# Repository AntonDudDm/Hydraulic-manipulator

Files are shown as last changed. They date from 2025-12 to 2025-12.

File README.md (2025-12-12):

# Hydraulic-manipulator

Проект многоосевого роботизированного манипулятора с механической,
электронной и программной частью.

Движение манипулятора осуществляется засчет гидравлических приводов.

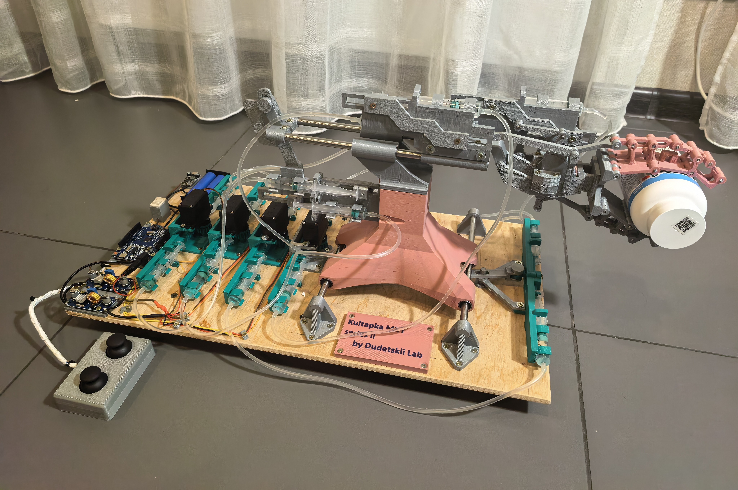
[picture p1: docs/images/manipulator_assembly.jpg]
Assembled Manipulator


## 📌 Доустигнутые цели проекта
- Моделирование кинематики и динамики
- Проектирование механической конструкции манипулятора
- Разработка управляющего ПО
- Управление сервоприводами / моторами
- Создание реального прототипа

## Структура проекта
```
Hydraulic-manipulator/
├── cad/ # SolidWorks модели (детали, сборки, чертежи)
├── firmware/ # Код микроконтроллера
├── software/ # ПК-скрипт для управления с компьютера
├── simulations/ # Математическое моделирование
└── docs/ # Документация, необходимые запчасти
```

## ⭐ Преимущества данного манипулятора

### 1️⃣ Преимущества, обусловленные гидравлическим приводом

Использование гидравлического привода обеспечивает ряд ключевых преимуществ по сравнению с электрическими и пневматическими системами:

* **Высокая удельная мощность**
  Гидравлические приводы позволяют развивать большие усилия и моменты при компактных габаритах исполнительных механизмов, что особенно важно для манипуляторов, работающих с тяжёлыми объектами.

* **Плавность и непрерывность движения**
  Гидравлика обеспечивает устойчивое и плавное управление скоростью и усилием, что критично при выполнении точных операций захвата и позиционирования.

* **Устойчивость к перегрузкам**
  В отличие от электроприводов, гидравлические системы лучше переносят кратковременные перегрузки без риска повреждения двигателя или редуктора.

* **Работоспособность в экстремальных условиях**
  Гидравлические системы менее чувствительны к:

  * высокой влажности,
  * пыли и загрязнениям,
  * вибрациям,
  * перепадам температур,
    что делает манипулятор пригодным для промышленной и полевой эксплуатации.

* **Высокая надёжность при длительной работе**
  При корректном проектировании гидросистема обладает большим ресурсом и стабильными характеристиками во времени.

---

### 2️⃣ Универсальная конструкция захвата

Особая конструкция хвата манипулятора обеспечивает возможность работы с широким спектром объектов:

* **Захват предметов различной формы и размеров**
  Конструкция позволяет эффективно работать как с:

  * цилиндрическими,
  * плоскими,
  * угловыми,
  * несимметричными объектами.

* **Адаптивность к положению объекта**
  Захват компенсирует неточности позиционирования и допускает небольшие ошибки ориентации, снижая требования к точности наведения манипулятора.

* **Надёжное удержание при минимальном давлении**
  Геометрия и кинематика хвата позволяют равномерно распределять усилие, уменьшая риск повреждения хрупких предметов.

* **Расширение области применения**
  Универсальный хват делает манипулятор пригодным как для:

  * технических,
  * так и для исследовательских и сервисных задач.

---

### 3️⃣ Дистанционное размещение гидравлических приводов

Конструкция манипулятора допускает вынос гидравлических приводов (насосов и моторов) за пределы рабочей зоны, что даёт принципиальные преимущества:

* **Повышенная безопасность эксплуатации**
  Манипулятор может работать в условиях:

  * радиационного заражения,
  * химически агрессивной среды,
  * повышенной температуры,
  * взрывоопасных зон,
    при этом основные силовые элементы остаются вне опасной области.

* **Снижение массы подвижных звеньев**
  Отсутствие тяжёлых моторов на самом манипуляторе:

  * уменьшает инерцию,
  * снижает нагрузки на конструкцию,
  * повышает точность и динамику движений.

* **Упрощение конструкции манипулятора**
  Механическая часть становится легче и конструктивно проще, что:

  * облегчает масштабирование,
  * повышает ремонтопригодность,
  * снижает требования к несущим элементам.

* **Повышение надёжности и ресурса системы**
  Дистанционное размещение приводов уменьшает тепловые и вибрационные нагрузки на манипулятор и электронные компоненты управления.

---

### 📌 Итог

Совокупность гидравлического привода, универсального хвата и возможности дистанционного размещения силовых элементов делает манипулятор:

* мощным,
* адаптивным,
* безопасным,
* пригодным для работы в экстремальных и потенциально опасных условиях.

Такая архитектура особенно перспективна для промышленной автоматизации, аварийно-спасательных и исследовательских задач.

---

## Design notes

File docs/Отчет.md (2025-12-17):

# Отчёт по разработке робототехнического манипулятора с гидравлическим приводом

## 1. Введение

В рамках инженерной подготовки была выполнена разработка робототехнического манипулятора, соответствующего заданной кинематической схеме. Проект охватывал полный цикл инженерной разработки: от анализа кинематики и концептуального проектирования до изготовления, сборки, электроники и программного управления.

Ключевой особенностью проекта является **использование полностью гидравлической системы привода**, реализованной на базе доступных компонентов и аддитивных технологий, что позволило исследовать альтернативные решения по сравнению с классическими электрическими и механическими приводами.

Assembled Manipulator

---

## 2. Цель и задачи работы

### 2.1 Цель работы

**Создание функционирующего робототехнического манипулятора, соответствующего заданной кинематической схеме, с использованием гидравлических приводов и электронного управления.**

---

### 2.2 Задачи работы

Для достижения поставленной цели в рамках проекта были решены следующие задачи:

1. Анализ заданной кинематической схемы манипулятора.
2. Разработка концепции механической реализации степеней свободы.
3. Исследование и сравнение различных типов приводов и передач.
4. Проектирование гидравлической системы привода.
5. Разработка механических узлов: кареток, направляющих, вращательных осей.
6. Проектирование и изготовление захватного устройства.
7. Изготовление деталей методом 3D-печати.
8. Разработка электрической схемы управления.
9. Реализация программного управления манипулятором.
10. Интеграция системы управления с клавиатурой и джойстиком.
11. Проведение финальных испытаний и анализа полученного результата.

---

## 3. Анализ кинематической схемы

На первом этапе был выполнен анализ заданной кинематической схемы манипулятора. Были определены:

* количество степеней свободы;
* типы кинематических пар (поступательные и вращательные);
* пространственное расположение осей;
* требования к диапазонам перемещений.

Анализ показал необходимость:

* реализации линейных перемещений с высокой плавностью;
* обеспечения вращательной степени свободы с достаточной жёсткостью;
* компактного и универсального схвата.

Результаты анализа легли в основу выбора конструктивных решений на последующих этапах.

---

## 4. Создание концепта и выбор механических решений

### 4.1 Концепция линейных перемещений

Для реализации поступательных степеней свободы были рассмотрены два варианта:

1. **Перемещение по направляющим с линейными подшипниками**
2. **Скользящее перемещение в пазах с сухим трением**

В ходе анализа и предварительных испытаний было установлено, что вариант с сухим трением:

* обладает повышенным сопротивлением движению;
* быстро изнашивается;
* снижает точность и повторяемость перемещений.

**Итоговое решение:**
Выбран вариант с **направляющими из нержавеющей стали и линейными подшипниками**, обеспечивающий минимальное трение, высокую плавность и долговечность.

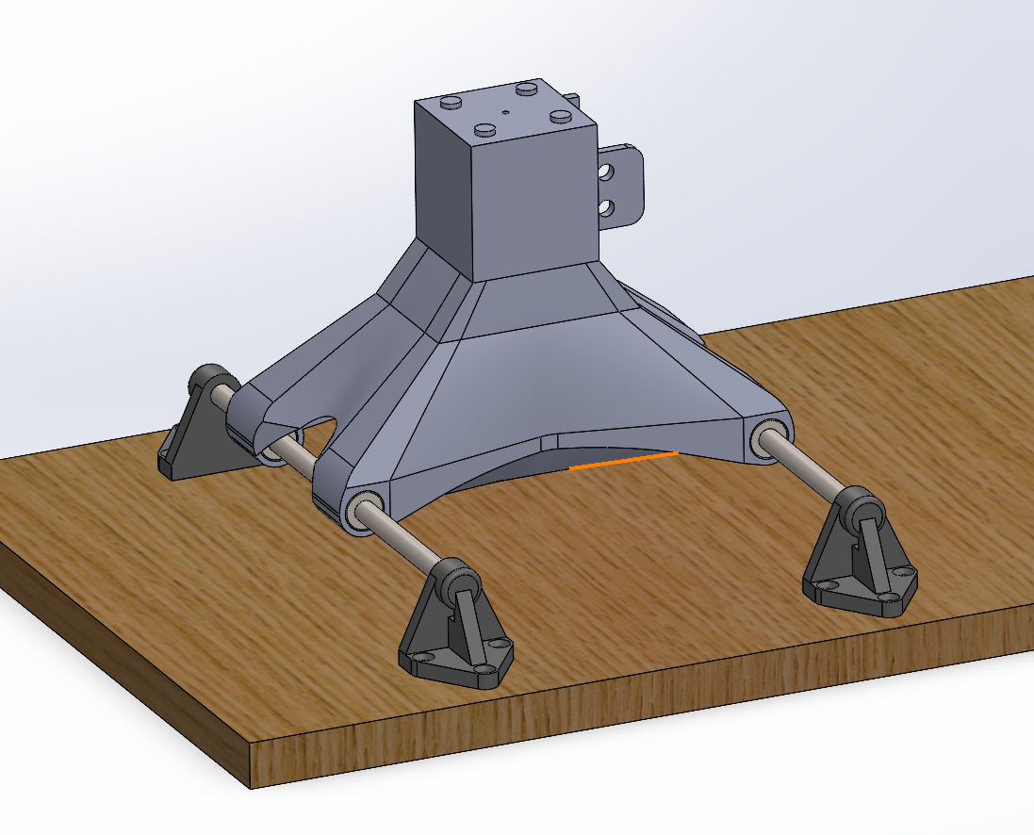
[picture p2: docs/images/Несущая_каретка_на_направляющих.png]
Несущая каретка


---

### 4.2 Выбор типа привода

Были рассмотрены следующие типы приводов:

* ремённая передача;
* винтовая передача;
* реечная передача;
* гидравлический привод.

#### Сравнение вариантов:

| Тип привода | Преимущества | Недостатки |
| --- | --- | --- |
| Ремённый | Простота, скорость | Люфты, растяжение |
| Винтовой | Точность | Сложность, трение |
| Реечный | Жёсткость | Шум, износ |
| Гидравлический | Большая сила, плавность, гибкость компоновки | Сложность герметизации |

**Итоговое решение:**
Выбран **гидравлический привод**, так как он:

* обеспечивает высокую выходную силу;
* позволяет легко преобразовывать вращательное движение в линейное;
* допускает вынесение приводов на расстояние от исполнительных механизмов;
* подходит для потенциальной работы в опасных условиях (радиация, загрязнения).

---

## 5. Разработка гидравлической системы

### 5.1 Комбинированные варианты

На ранних этапах рассматривались гибридные решения:

* гидравлика + механическая передача;
* гидравлика + тросовая передача.

Однако они показали:

* усложнение конструкции;
* рост люфтов;
* снижение надёжности.

### 5.2 Полностью гидравлическая система

В результате было принято решение о реализации **полностью гидравлической системы**.

---

### 5.3 Выбор конфигурации гидроцилиндров

Рассматривались два варианта:

1. **Одноцилиндровая система**
2. **Двуцилиндровая система**

В ходе тестирования было установлено, что:

* одноцилиндровая система имеет неравномерное распределение усилий;
* двуцилиндровая система обеспечивает лучшую симметрию, устойчивость и плавность.

**Итог:** выбран **двуцилиндровый вариант**.

---

### 5.4 Разработка гидронасоса

Из-за невозможности напечатать герметичный цилиндр на используемом 3D-принтере было принято инженерное решение:

* использовать **медицинские шприцы** как готовые герметичные гидроцилиндры.

Был разработан **двуцилиндровый гидронасос на основе шприцов**, обеспечивающий:

* надёжную герметизацию;
* простоту изготовления;
* повторяемость параметров.

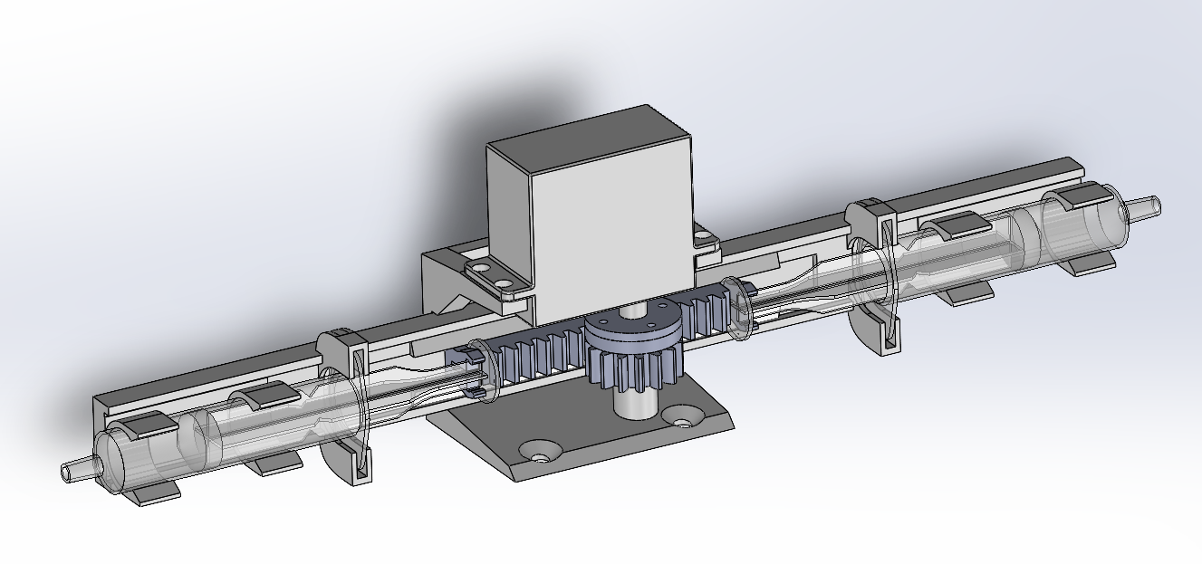
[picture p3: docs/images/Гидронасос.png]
Гидронасос


---

## 6. Проектирование механических узлов

### 6.1 Каретки и направляющие

Были разработаны:

* подвижные каретки;
* узлы крепления направляющих;
* посадочные места для линейных подшипников.

Особое внимание уделялось:

* жёсткости конструкции;
* минимизации перекосов;
* простоте сборки и обслуживания.

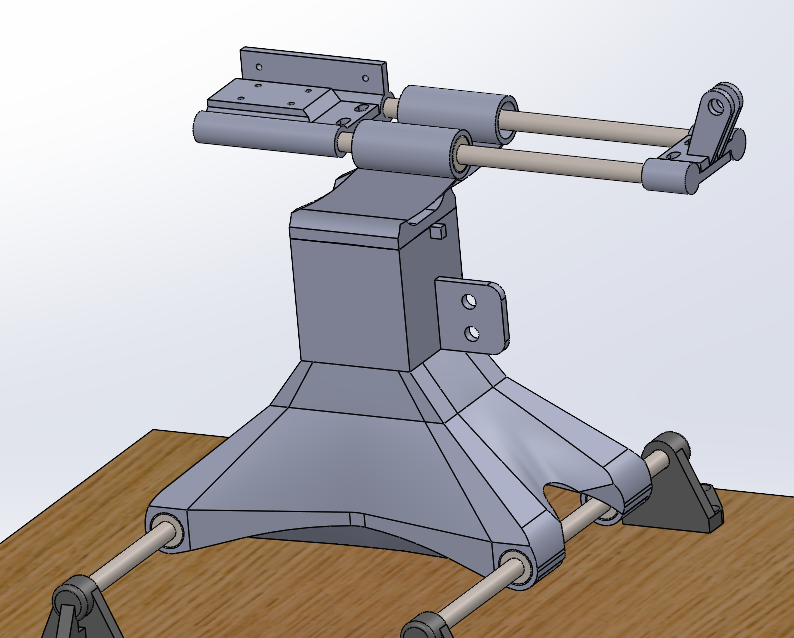
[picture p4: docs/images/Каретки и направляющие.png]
Каретки


---

### 6.2 Линейные гидромоторы

Для каждой линейной оси были разработаны гидравлические приводы, передающие усилие напрямую на каретки, что позволило отказаться от промежуточных механических передач.

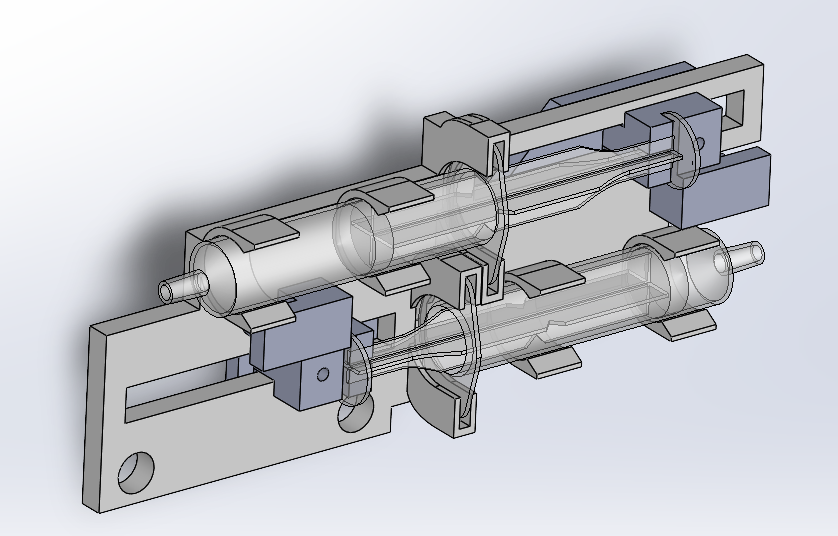
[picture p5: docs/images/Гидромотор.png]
Гидромотор


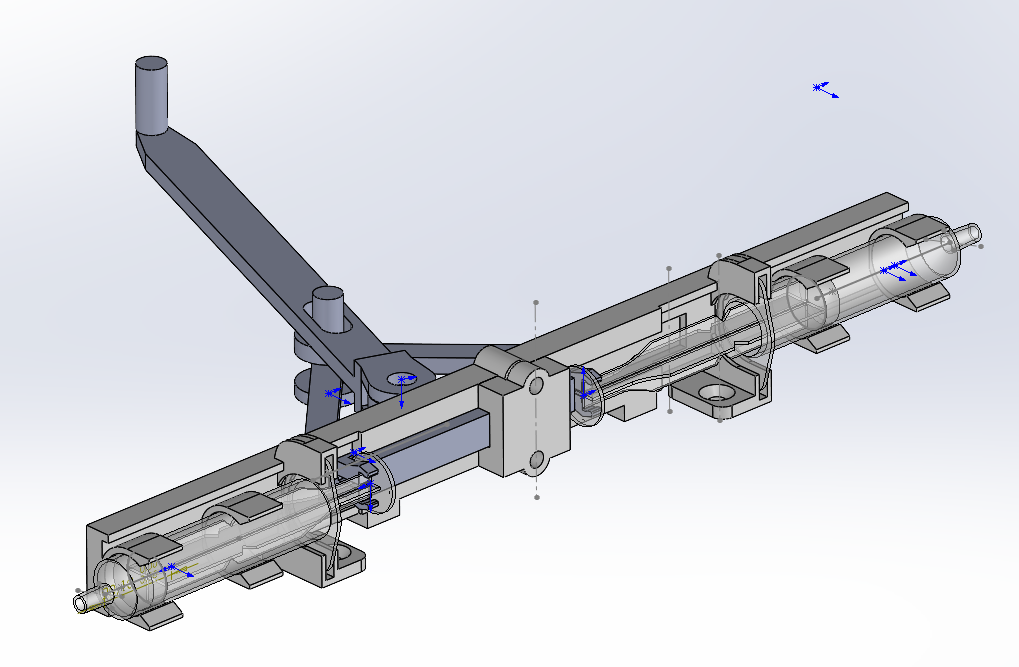
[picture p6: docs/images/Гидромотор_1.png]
Гидромотор


---

### 6.3 Вращательная ось

Первая версия вращательной оси показала:

* избыточную подвижность;
* наличие люфтов под нагрузкой.

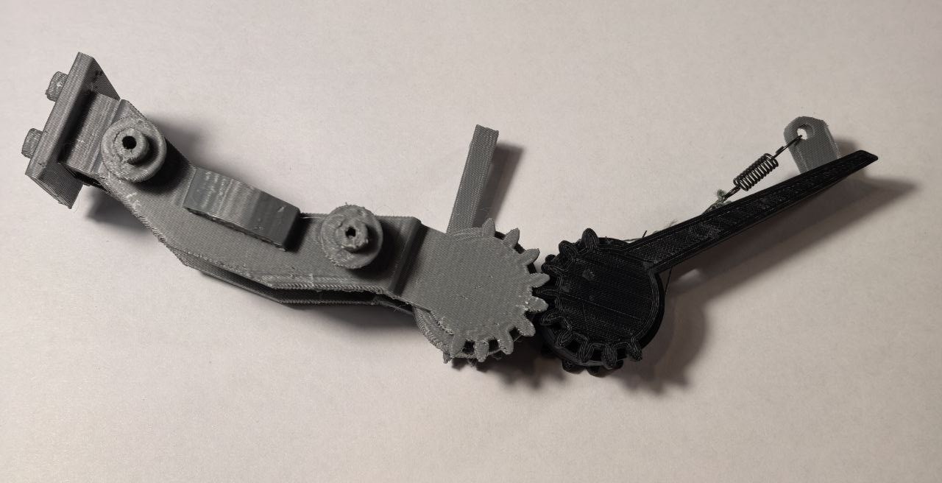
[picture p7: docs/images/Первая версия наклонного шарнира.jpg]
Шарнир версия 1


После анализа была разработана **упрощённая и более жёсткая конструкция с одной тягой**, обеспечивающая:

* снижение люфтов;
* повышение надёжности;
* упрощение сборки.

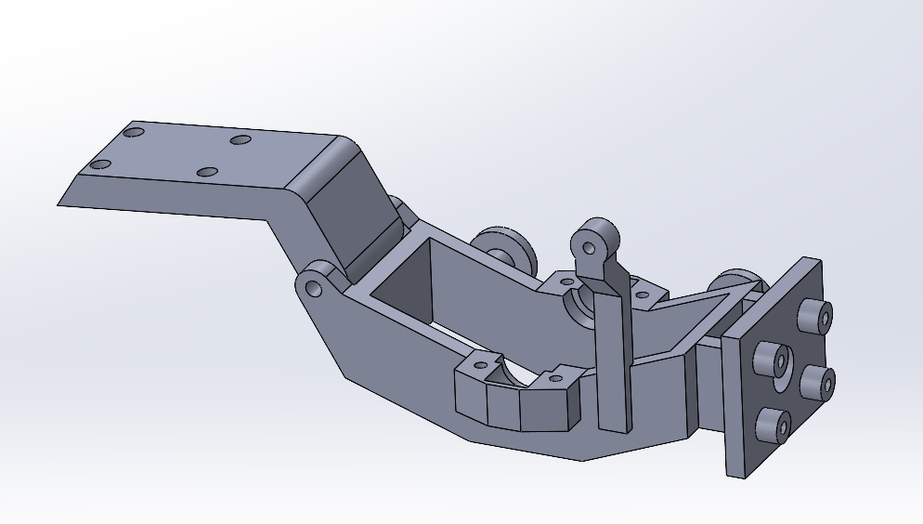
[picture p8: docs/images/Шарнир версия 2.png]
Шарнир версия 2


---

## 7. Проектирование захватного устройства

### 7.1 Анализ типов захватов

Были рассмотрены:

* параллельные захваты;
* клещевые захваты;
* вакуумные захваты;
* антропоморфные захваты.

### 7.2 Выбор антропоморфного захвата

Был выбран **антропоморфный тип захвата**, так как он:

* универсален;
* способен захватывать объекты сложной формы;
* адаптируется к различным размерам и геометрии объектов.

---

### 7.3 Концепция сухожилий и фаланг

Захват был реализован на основе:

* фалангов пальцев;
* сухожильной передачи усилия.

Это позволило:

* равномерно распределять усилие;
* обеспечить адаптивность захвата.

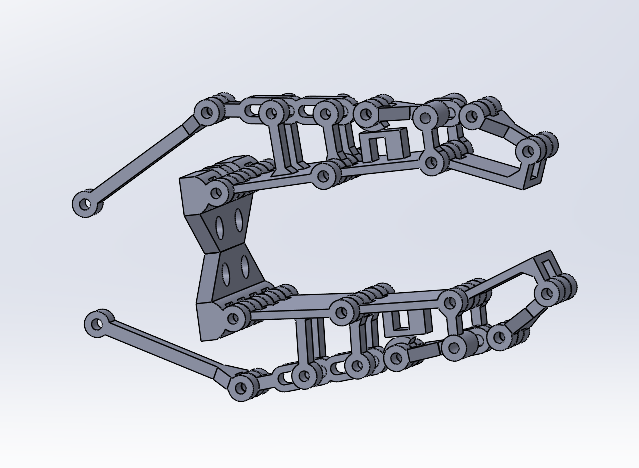
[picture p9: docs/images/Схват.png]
Схват


---

### 7.4 Планетарная передача

Для передачи усилия от гидронасоса к захвату была разработана **планетарная передача**, обеспечивающая:

* компактность;
* соосность конструкции;
* эффективное распределение момента на нижнюю и верхнюю части cхвата.

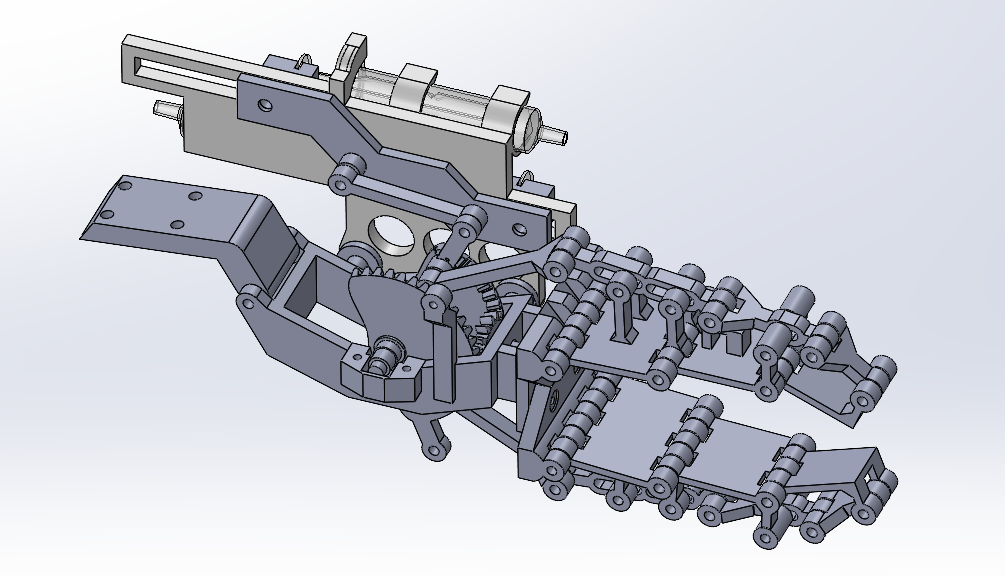
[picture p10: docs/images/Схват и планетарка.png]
Схват и планетрака


---

## 8. Изготовление и сборка

### 8.1 Прототипирование

На этапе прототипирования:

* выполнялась печать отдельных модулей;
* производилась подгонка тяг и подвижных элементов;
* неудачные образцы перепечатывались.

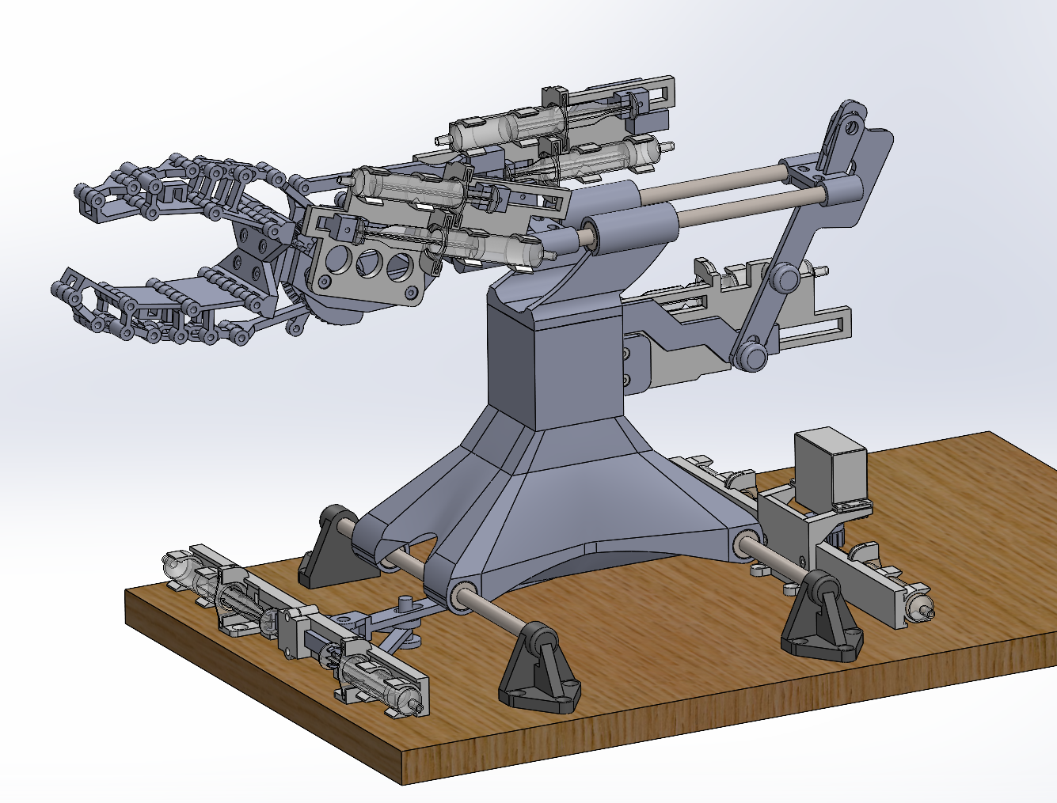
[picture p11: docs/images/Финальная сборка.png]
Сборка


### 8.2 Финальная сборка

После доработки всех элементов была выполнена **финальная сборка механической части манипулятора**.

---

## 9. Электроника и питание

### 9.1 Начальная схема

Изначально использовалось питание от Arduino, однако было выявлено, что:

* напряжение и ток недостаточны для питания серводвигателей.

### 9.2 Раздельное питание

Было реализовано раздельное питание:

* Arduino;
* серводвигателей.

С использованием **двух понижающих DC-DC преобразователей**.

---

### 9.3 Аккумуляторная система

В систему были добавлены:

* литий-ионные аккумуляторы 18650;
* модуль зарядки с BMS;
* выключатель питания.

После этого была выполнена окончательная пайка схемы.

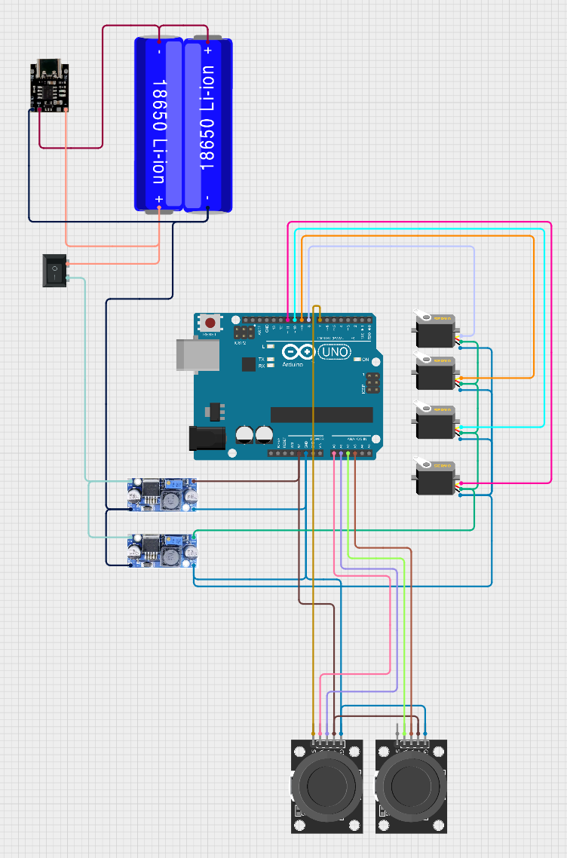
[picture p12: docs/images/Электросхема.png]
"Электросхема"


---

## 10. Программное обеспечение

### 10.1 Управляющий скетч Arduino

Был разработан скетч, который:

* обеспечивает непрерывное вращение моторов при наличии управляющего сигнала;
* мгновенно останавливает движение при отсутствии сигнала, что повышает безопасность.

---

### 10.2 Управление с компьютера

Был создан Python-скрипт для:

* передачи команд через COM-порт;
* управления манипулятором с клавиатуры.

---

### 10.3 Управление джойстиком

После этого:

* была разработана модель управления джойстиком;
* скетч Arduino был переписан для поддержки модуля KY-023.

---

## 11. Использованные компоненты

### Механика и гидравлика

* 4 серво-привода MG945-360
* 4 направляющие из нержавеющей стали (220 мм, Ø8 мм)
* 4 линейных подшипника LM8UU
* 4 линейных подшипника LM8-L-UU (8×15×45 мм)
* 16 шприцов по 5 мл
* Медицинские капельницы (в качестве гидравлических шлангов)
* Пластик PLA

### Электроника

* Arduino UNO
* 2 понижающих DC-DC преобразователя LM2596S
* Модуль зарядки Li-ion аккумуляторов с BMS
* Модуль двухосевого джойстика KY-023
* 2 Li-ion аккумулятора 18650 (3.7 В)

---

## 12. Итоговые испытания

В ходе финальных тестов было подтверждено:

* работоспособность всех степеней свободы;
* корректность гидравлической системы;
* устойчивость конструкции под нагрузкой;
* удобство управления с клавиатуры и джойстика.

---

## 13. Выводы и направления улучшения

### Выводы:

* Цель работы была полностью достигнута.
* Создан функционирующий манипулятор, соответствующий заданной кинематической схеме.
* Гидравлический привод показал свою эффективность и перспективность.
* Использование доступных компонентов позволило реализовать сложную систему с минимальными затратами.

### Возможные улучшения:

* внедрение датчиков положения и давления;
* реализация замкнутых контуров управления;
* повышение точности позиционирования;
* использование более прочных материалов;
* переход к промышленным гидравлическим компонентам.

---

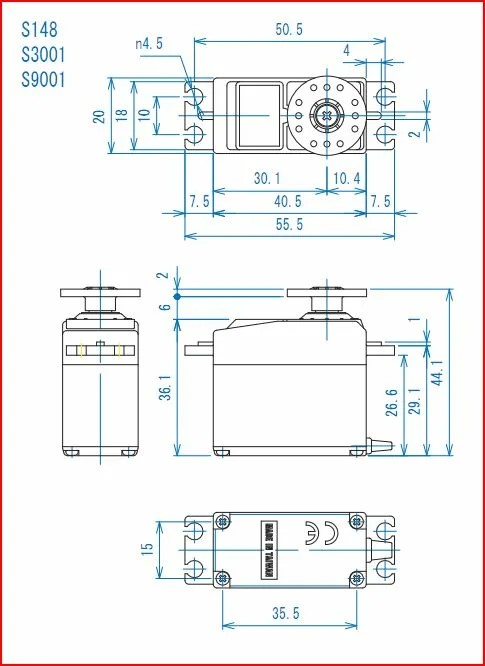
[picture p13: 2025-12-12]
CAD/Гидронасос/Сервопривод/Чертежь сервопривода (Покупной).jpg

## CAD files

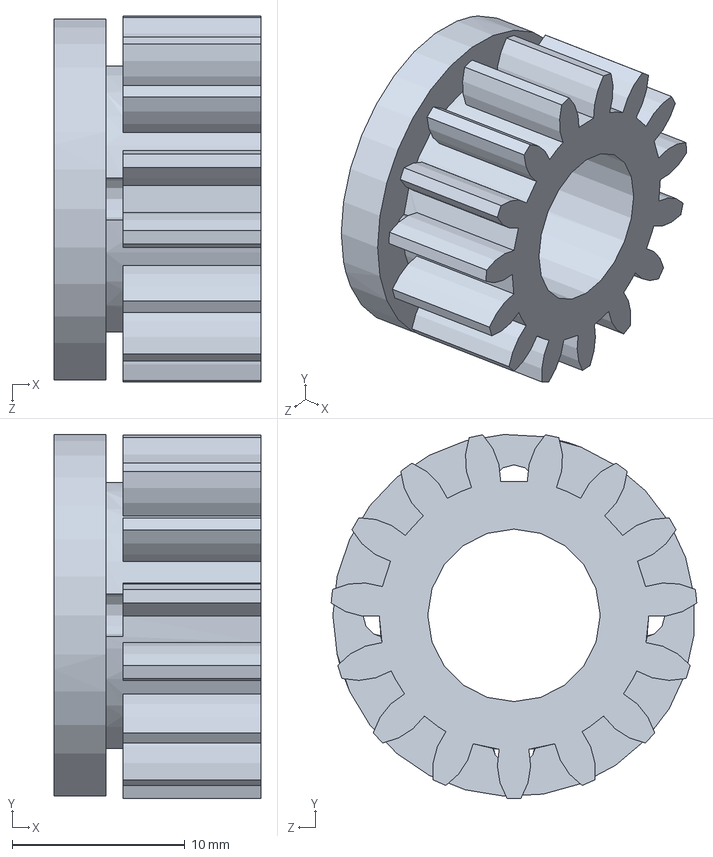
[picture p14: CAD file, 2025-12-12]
CAD/Гидронасос/Детали гидронасос/Звездочка к сервоприводу.SLDPRT
12.0 x 21.1 x 21.2 mm

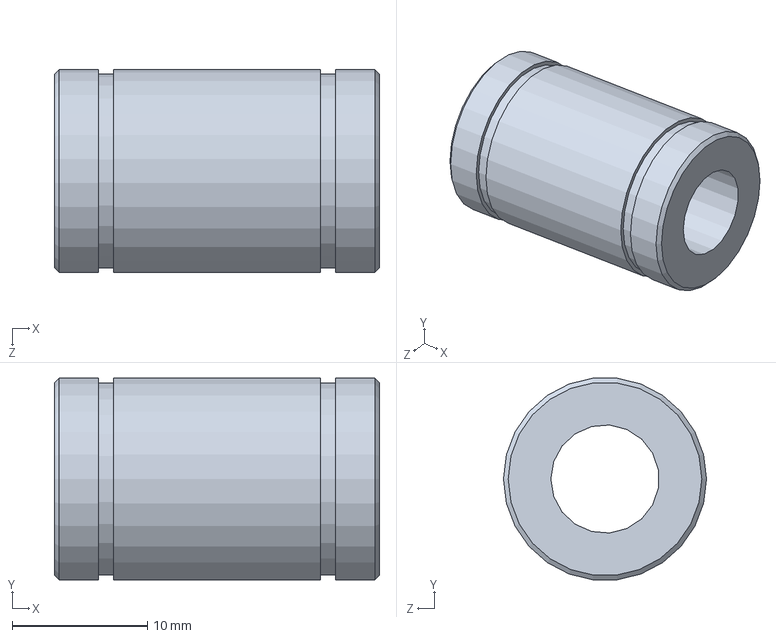
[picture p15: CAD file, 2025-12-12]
CAD/Детали и крепления сборки/подшибник скольжения 8 мм. 15 мм. 24 мм..SLDPRT
24.0 x 14.9 x 15.0 mm

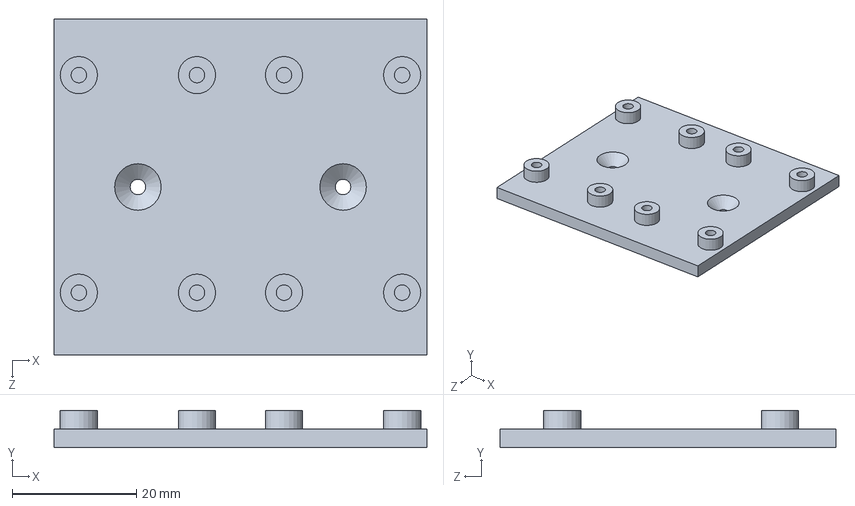
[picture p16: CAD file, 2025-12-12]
CAD/Детали под электронику/Крепеж понижающих преобразователей.SLDPRT
60.0 x 6.00 x 54.0 mm

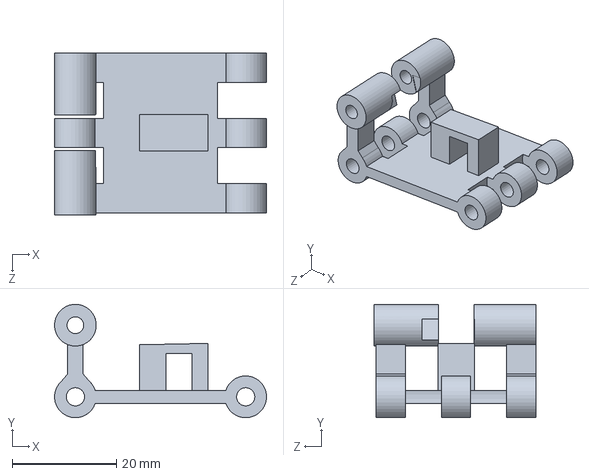
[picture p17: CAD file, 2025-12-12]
CAD/Захват и мотор №4/Захват/Детали фаланги/2 фаланга.SLDPRT
40.6 x 21.7 x 31.0 mm

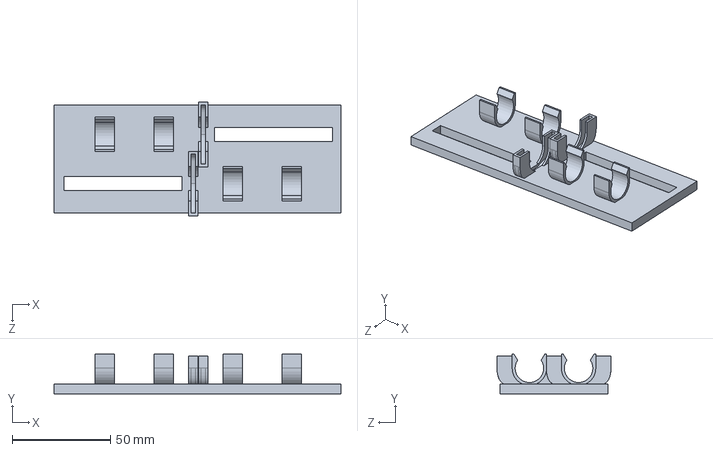
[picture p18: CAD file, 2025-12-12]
CAD/Захват и мотор №4/Мотор №4/Детали мотор №4/Крепёж под шприц мотор №4.SLDPRT
145.8 x 20.2 x 58.0 mm

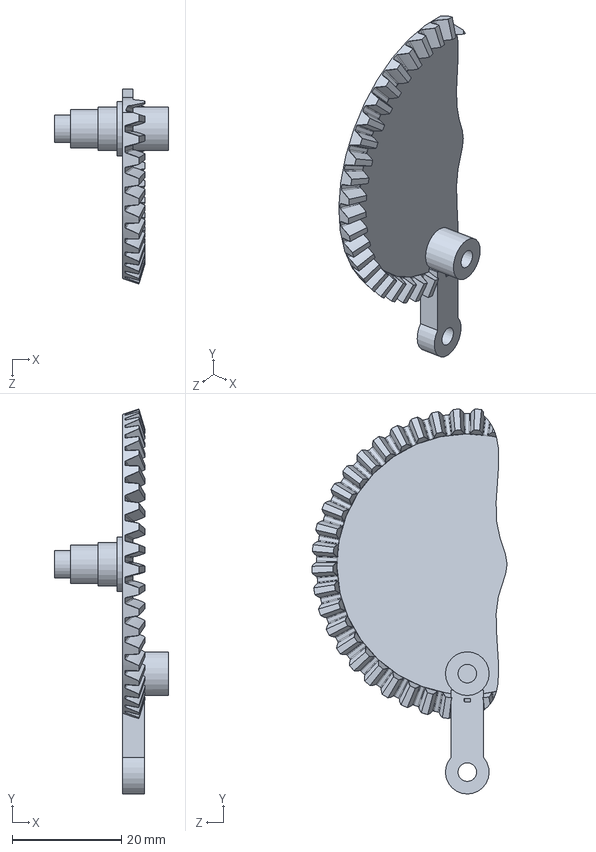
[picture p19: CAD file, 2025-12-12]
CAD/Захват и мотор №4/Планетарная передача/Детали планетарка/Планетарка.SLDPRT
20.9 x 70.4 x 35.7 mm

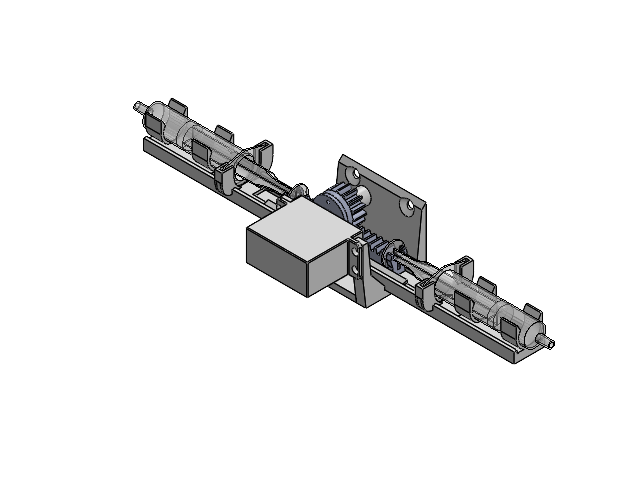
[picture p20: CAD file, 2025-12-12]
CAD/Гидронасос/Сборка Гидронасос.SLDASM
крепёж под шприц, нагнетатель
рейка на гидронасос
шприц корпус 5 мм x 2
шприц шток 5 мм x 2
звездочка
корпус
прицепная шайба
крепёж к столу

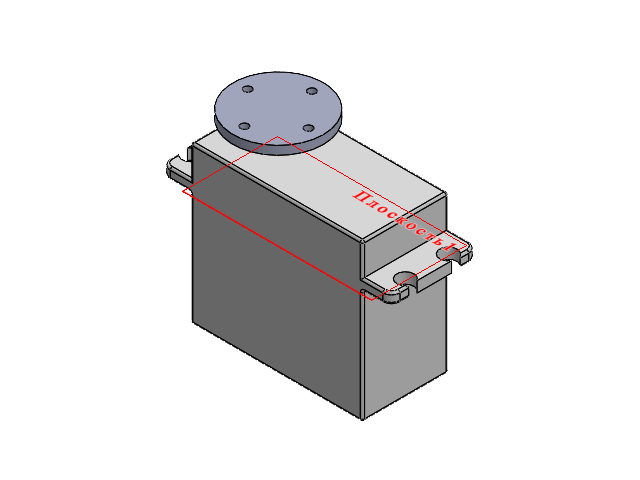
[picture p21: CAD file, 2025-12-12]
CAD/Гидронасос/Сервопривод/Сервопривод сборка.SLDASM
корпус
прицепная шайба

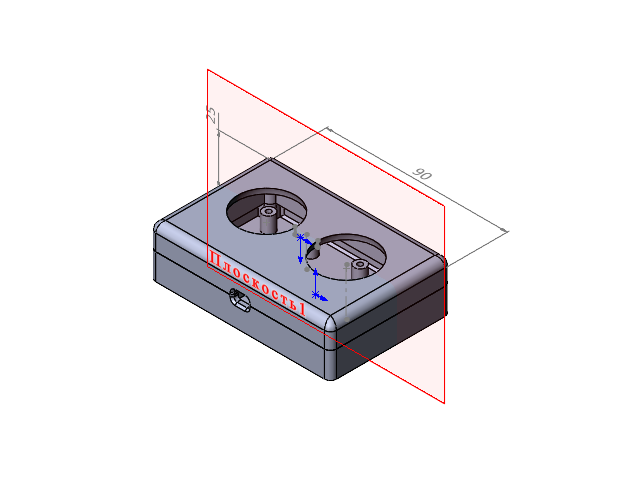
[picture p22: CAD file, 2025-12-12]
CAD/Детали под электронику/Джойстик/Сборка джойстик.SLDASM
Нижняя часть коробки под Джойстик
Верхняя часть коробки под Джойстик

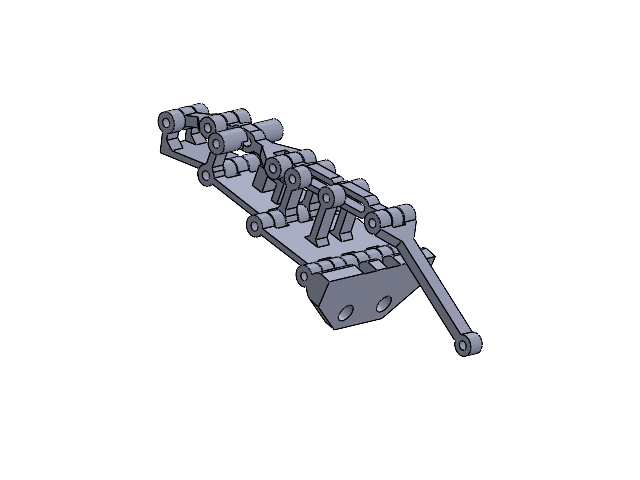
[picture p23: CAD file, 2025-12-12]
CAD/Захват и мотор №4/Захват/Сборка фаланги захвата.SLDASM
начало
1 фаланга верх
2 фаланга верх
3 фаланга верх
тяга 1 фаланга
тяга 2 фаланга
тяга 3 фаланга
тяга 4 фаланга

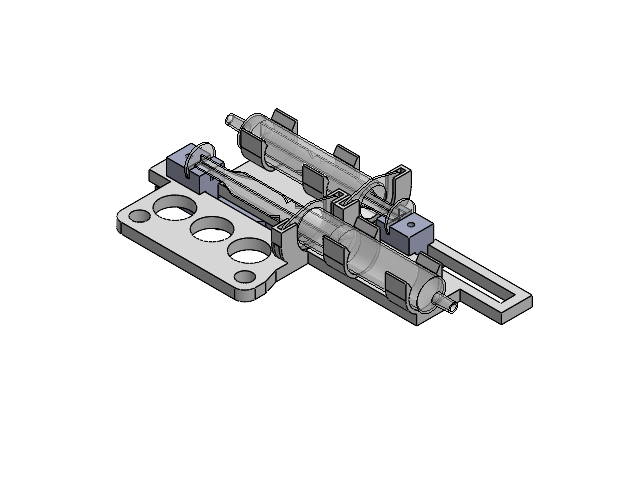
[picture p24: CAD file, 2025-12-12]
CAD/Захват и мотор №4/Мотор №4/Мотор №4 сборка.SLDASM
крепёж под шприц мотор 4
шприц корпус 5 мм x 2
шприц шток 5 мм x 2
крепёж штока мотора 4 x 2
подвижный элемент4

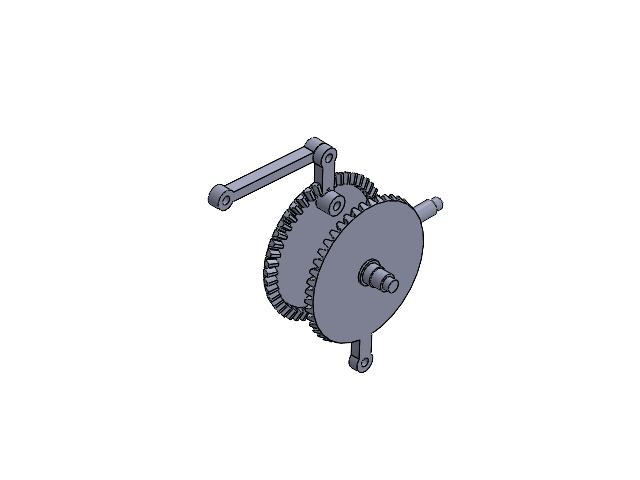
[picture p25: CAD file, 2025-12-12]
CAD/Захват и мотор №4/Планетарная передача/Сборка Планетарная передача.SLDASM
планетарка 1 x 2
сателит 1
тяга на мотор

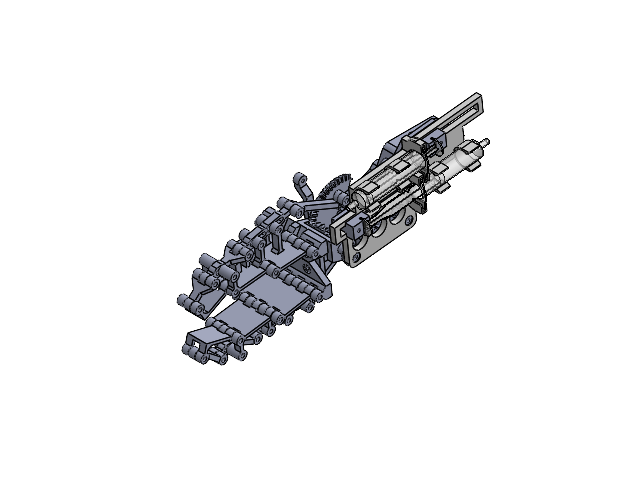
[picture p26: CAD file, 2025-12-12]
CAD/Захват и мотор №4/Сборка захвата.SLDASM
крепёж шарнира
шарнир на руку 2
планетарка 1 x 2
сателит 1
тяга на мотор
крепёж под шприц мотор 4
шприц корпус 5 мм x 2
шприц шток 5 мм x 2
крепёж штока мотора 4 x 2
подвижный элемент4
начало x 2
1 фаланга верх x 2
2 фаланга верх x 2
3 фаланга верх x 2
тяга 1 фаланга x 2
тяга 2 фаланга x 2
тяга 3 фаланга x 2
тяга 4 фаланга x 2

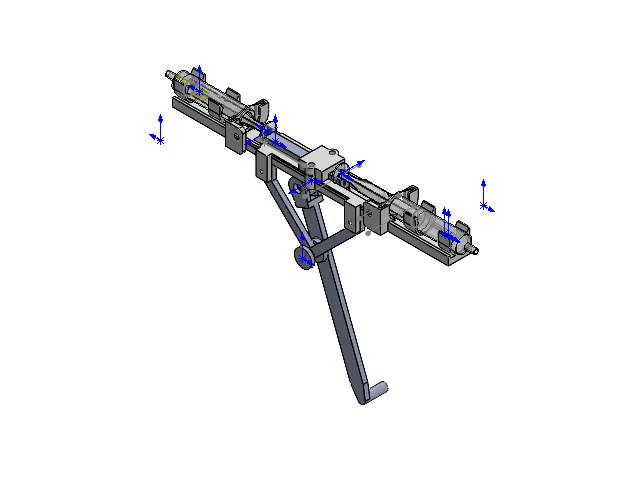
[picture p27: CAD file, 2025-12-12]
CAD/Мотор №1/Мотор №1 сборка.SLDASM
крепёж под шприц, мотор
рейка на гидромотор
шприц корпус 5 мм x 2
шприц шток 5 мм x 2
подставка под рычаг
тяга с шайбой
крепёж штока

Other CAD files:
CAD/Мотор №2/Мотор №2 сборка.SLDASM
CAD/Мотор №3/Мотор №3 сборка.SLDASM
CAD/Сборка Манипулятора.SLDASM
CAD/Шприц/шприц сборка.SLDASM
CAD/Гидронасос/Детали гидронасос/Крепёж к платформе.SLDPRT
CAD/Гидронасос/Детали гидронасос/Крепёж под шприц, нагнетатель.SLDPRT
CAD/Гидронасос/Детали гидронасос/Рейка на гидронасос.SLDPRT
CAD/Гидронасос/Сервопривод/Корпус сервопривода.SLDPRT
CAD/Гидронасос/Сервопривод/Прицепная шайба.SLDPRT
CAD/Детали и крепления сборки/Крепёж рельсовых.SLDPRT
CAD/Детали и крепления сборки/Несущая каретка.SLDPRT
CAD/Детали и крепления сборки/Рельсовая прут 8 мм. 220 мм..SLDPRT
CAD/Детали и крепления сборки/Шилдик.SLDPRT
CAD/Детали и крепления сборки/Штифт 1 ось свободы.SLDPRT
CAD/Детали и крепления сборки/Штифт 2 ось свободы.SLDPRT
CAD/Детали и крепления сборки/стол фанера 18.мм..SLDPRT
CAD/Детали под электронику/Джойстик/Коробка под джойстик Верх.SLDPRT
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

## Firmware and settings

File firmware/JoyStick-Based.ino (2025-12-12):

#include <Servo.h>

/* ========= НАСТРОЙКИ ========= */

// Пины сервоприводов (сигналы)
const uint8_t SERVO_PINS[4] = {9, 10, 8, 11};

// Пины джойстиков
// Джойстик 1
const uint8_t J1_X = A0;
const uint8_t J1_Y = A1;
const uint8_t J1_SW = 4;     // кнопка (замыкает на GND)
// Джойстик 2
const uint8_t J2_X = A2;
const uint8_t J2_Y = A3;
const uint8_t J2_SW = 7;     // кнопка (замыкает на GND)

// Калибровка стопа и пределов для КАЖДОГО мотора (можно подстроить отдельно)
int STOP_PWM[4] = {90, 90, 90, 90};  // при этих значениях моторы стоят
int MAX_FWD[4]  = {110,110,110,110}; // максималка вперёд  (> STOP)
int MAX_BACK[4] = {70, 70, 70, 70};  // максималка назад   (< STOP)

// Мёртвая зона вокруг центра стика (0..1023). 40–80 обычно норм.
const int DEADZONE = 60;

// Инвертирование осей (если «вперёд» крутится «назад» — поставьте true)
bool INV_AXIS[4] = {false, false, false, false};
// порядок: [S1=J1_X, S2=J1_Y, S3=J2_X, S4=J2_Y]

/* ========= ВНУТРЕННЕЕ ========= */

Servo srv[4];

/* Преобразуем положение оси (0..1023) → PWM для сервопривода непрерывного вращения.
   512 — центр. В DEADZONE возвращаем стоп.
   За пределами — линейно до MAX_FWD/MAX_BACK. */
int axisToPwm(int raw, int idx, bool invert) {
  // центрируем
  int c = raw - 512;

  // инвертирование
  if (invert) c = -c;

  // мёртвая зона
  if (abs(c) <= DEADZONE) return STOP_PWM[idx];

  // "обрезаем" DEADZONE, нормируем к диапазону [0..1]
  float norm;
  if (c > 0) {
    norm = float(c - DEADZONE) / float(512 - DEADZONE);
    // вперёд: STOP -> MAX_FWD
    float pwm = STOP_PWM[idx] + norm * (MAX_FWD[idx] - STOP_PWM[idx]);
    if (pwm > MAX_FWD[idx]) pwm = MAX_FWD[idx];
    return int(pwm + 0.5f);
  } else {
    norm = float((-c) - DEADZONE) / float(512 - DEADZONE);
    // назад: STOP -> MAX_BACK
    float pwm = STOP_PWM[idx] - norm * (STOP_PWM[idx] - MAX_BACK[idx]);
    if (pwm < MAX_BACK[idx]) pwm = MAX_BACK[idx];
    return int(pwm + 0.5f);
  }


  
}

void writeStopAll() {
  for (int i = 0; i < 4; ++i) srv[i].write(STOP_PWM[i]);
}

void setup() {

  //Serial.begin(9600);
  //Serial.println("=== Joystick control debug start ===");
  
  // Сервы
  for (int i = 0; i < 4; ++i) {
    srv[i].attach(SERVO_PINS[i]);
  }
  writeStopAll();

  // Кнопки джойстиков — внутренние подтяжки (замыкают на GND при нажатии)
  pinMode(J1_SW, INPUT_PULLUP);
  pinMode(J2_SW, INPUT_PULLUP);

  // Аналоговые пины — просто читаем analogRead(...)
  // Можно добавить усреднение/фильтр при желании

  // Небольшая пауза на старт
  delay(300);
}

void loop() {
  // 1) Чтение осей
  int j1x = analogRead(J1_X);  // 0..1023
  int j1y = analogRead(J1_Y);
  int j2x = analogRead(J2_X);
  int j2y = analogRead(J2_Y);

  // 2) Кнопки: если нажали любой (LOW) — стоп всем
  bool stopPressed = (digitalRead(J1_SW) == LOW) || (digitalRead(J2_SW) == LOW);
  if (stopPressed) {
    writeStopAll();
  } else {
    // 3) Преобразуем оси -> PWM и пишем на сервы
    // Соответствие: S1=J1_X, S2=J1_Y, S3=J2_X, S4=J2_Y
    int pwm1 = axisToPwm(j1x, 0, INV_AXIS[0]);
    int pwm2 = axisToPwm(j1y, 1, INV_AXIS[1]);
    int pwm3 = axisToPwm(j2x, 2, INV_AXIS[2]);
    int pwm4 = axisToPwm(j2y, 3, INV_AXIS[3]);

      // Печать отладки
    //Serial.println(pwm1);
    //Serial.println(pwm2);
    //Serial.println(pwm3);
    //Serial.println(pwm4);

    srv[0].write(pwm1);
    srv[1].write(pwm2);
    srv[2].write(pwm3);
    srv[3].write(pwm4);
  }

  // период опроса 10–20 мс — норм
  delay(15);
}

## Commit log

2025-12-12 created git repository
    [1 фаланга.SLDPRT, 2 фаланга.SLDPRT, 3 фаланга.SLDPRT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]
2025-12-15 create Отчет
2025-12-15 rebuild Отчет
2025-12-15 move отчет
2025-12-17 complite отчет
